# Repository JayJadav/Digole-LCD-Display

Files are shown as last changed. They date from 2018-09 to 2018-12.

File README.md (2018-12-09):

# Build Instructions - Broadcom Development Platform: Digole LCD with Touch Capabilities
#### By Jacob Ladan • For Hardware Production Technology CENG 317, Humber College School of Applied Technology
<br />

## Table of Contents
- [Introduction](#introduction)
- [Build Materials and Budget](#build-materials-and-budget)
- [Time Commitment](#time-commitment)
- [Mechanical Assembly](#mechanical-assembly)
- [PCB and Soldering](#pcb-and-soldering)
- [Powering Up Device](#powering-up-device)
- [The Software](#the-software)
- [Testing](#testing)
- [Finished Product](#finished-product)
- [Resources](#resources)
<br />

## Introduction
As a result of following these build instructions, the builder will be able to implement a Digole LCD screen with a Raspberry Pi 3B+.
These build instructions will aid the builder in producing a unified product, along with the necessary code to drive these devices. 
The builder will connect the LCD screen to the Pi with the aid of a custom designed PCB, and utilize a small program in order to read a 
string from a user through the Pi's terminal and print it to the LCD. The program will be written in C and the interface used to connect the 
Pi and the LCD will be I squared C (I2C).

The following image depicts the overall goal of the hardware project for the third year capstone of the Computer Engineering Technology 
program at Humber College. This includes two other projects that are to be implemented at a later date, as well as a communication with 
a remotely hosted database. 

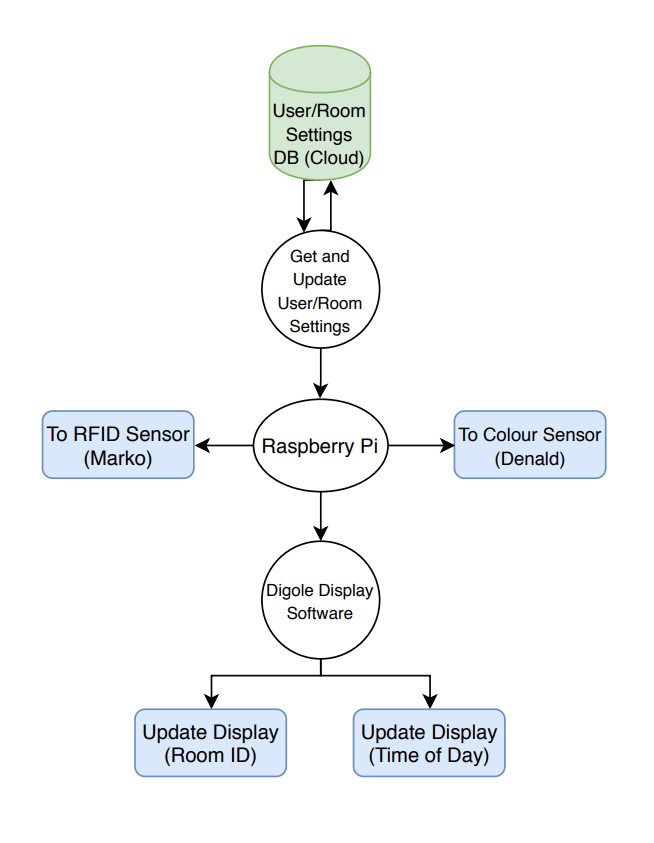
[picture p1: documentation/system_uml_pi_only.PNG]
SystemUML


For the purpose of these build instructions and what will be focused on, the following image depicts an initial version to introduce 
the builder to interfacing a Pi with an LCD screen. This allows the builder to use what has been produced through these instructions and apply it how they see fit. 

BISystemUML

#### The finished product, and what will be achieved through following these instructions.

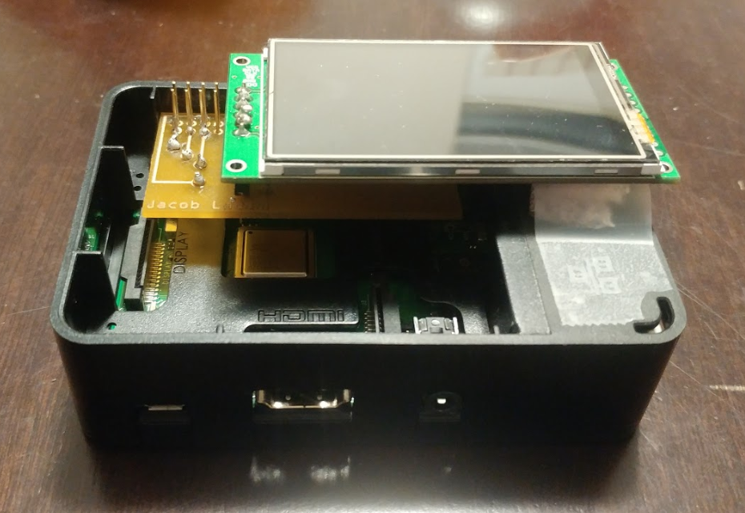
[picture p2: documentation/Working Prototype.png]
FinishedProduct


#### Helpful skills a builder should have before beginning:
- Familiarity with a linux shell environment for navigating the Raspberry Pi console
- Breadboarding
- Soldering
- Some knowledge of programming (C is most helpful)

A weekly updated blog for the fall semester of 2018 for this project as it was designed and implemented can be viewed [here](https://jacobladan.github.io/Digole-LCD-Display/).
<br />

## Build Materials and Budget
A full list of materials along with a detailed view of costs can be downloaded form within this repository [here](https://github.com/jacobladan/Digole-LCD-Display/blob/master/documentation/Budget.xlsx).
The total cost of producing this project is heavily inflated due to the cost of the soldering kit that was supplied in the lab during
development. Any generic solding iron can be used for this project.

The total cost after removing the soldering kit is: **$398.27 CAD** after HST. This includes all the tools used in completing the project (eg. wirecutters, needlenose pliers, breadboard, etc.)

Notable purchases include: Raspberry Pi 3B+ Kit ($94.95 CAD) and Digole 2.4" LCD display with touch capabilities ($17.49 USD).
<br />

## Time Commitment
A detailed view of the schedule followed this semster can be downloaded from within this repository [here](https://github.com/jacobladan/Digole-LCD-Display/blob/master/documentation/Capstone%20Gantt%20Schedule.mpp). 
This schedule uses a weekly breakdown that follows the CENG 317 class schedule for the fall semester of 2018. This project could be completed in a more compact time frame if the builder so chooses. The schedule is helpful in outlining the overall flow and the order in which each milestone for the project is completed. Orignally the project was completed over a 15 week semester, however it could more reasonably be completed in 1-2 week(s) dependant on how many of the materials the builder already possesses, access to the facilities necessary in producing the PCB, and shipping times. 
<br />

## Mechanical Assembly
Firstly, in order for the Digole LCD to use I2C communication with the Pi, one modification must be made to the screen's logic board. The builder must solder a  short between the middle and the I2C adapters as outlined in the image below.

I2CShort

Next, the following connection scheme will be used in order to connect the Digole LCD to the Raspberry Pi's GPIO pins. 

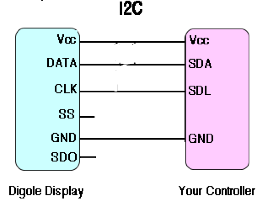
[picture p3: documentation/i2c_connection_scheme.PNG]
I2CConnection


The LCD will be connected to a breadboard, and the following connections will be made from the board to the GPIO pins on the Pi. With GPIO on the left and the coorisponding LCD connections on the right. The SS and SDO pins on the LCD will be left open:
- Pin01(3.3V) --> VCC 
- Pin03(BCM 2 Data) --> DATA
- Pin05(BCM 3 Clock) --> CLK 
- Pin06(Ground) --> GND

As a result the builder will now have produced something similar to the construction depicted below. 

BreadboardConection

Note: A 6 pin header has been soldered to the LCD's connectors in order to allow it to attach properly to the breadboard and later the PCB. 

With the Pi powered on, and I2C communications enabled, the LCD will power on and display its factory default message indicating that proper power has been supplied, ground has been connected, and the LCD is in working order. 

Next, to ensure the LCD has been connected properly for I2C communications, the following command should be entered in to the Pi's terminal: ```sudo i2cdetect -y 1```. This will display a simple graphic listing each device connected to the I2C bus and it's corrisponding address. The address the LCD uses is 0x27.

i2cdetect
<br />

## PCB and Soldering
The following PCB was designed and used for this project. The Gerber files for the PCB can be found from within this repository [here](https://github.com/jacobladan/Digole-LCD-Display/tree/master/documentation/Gerber%20Files%20V2.0). Included in these files is a save for the application **Fritzing** which was used to produce this design. This file can be opened and used by the same program to add any modifications to the board as the builder should see fit. Such as, their own name and a description. 

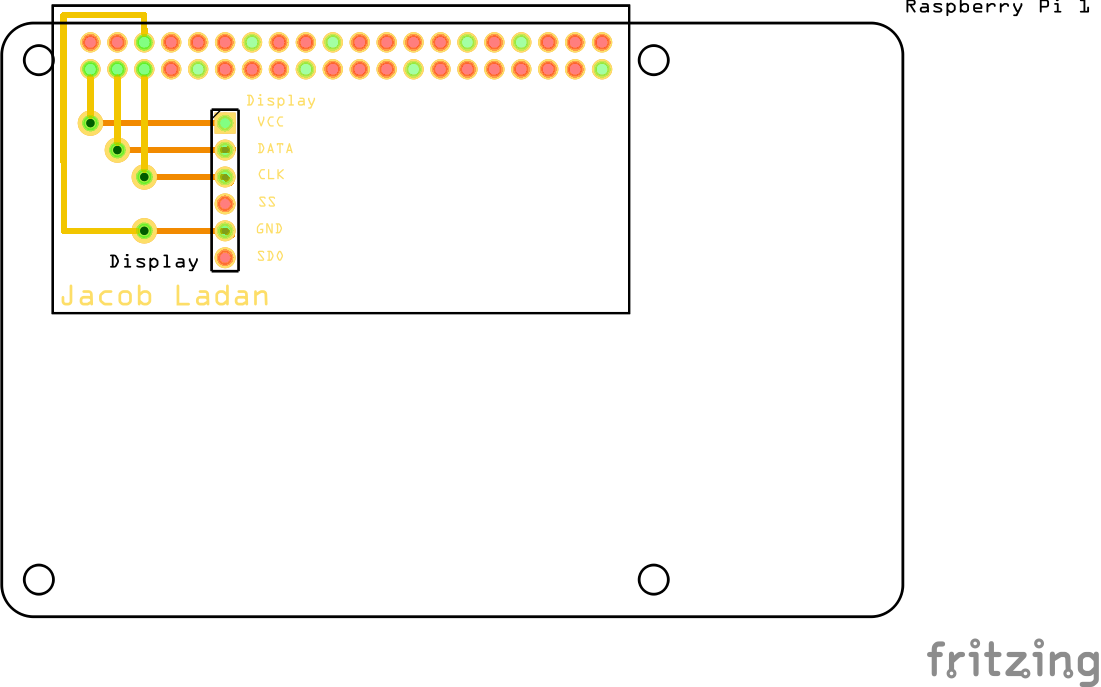
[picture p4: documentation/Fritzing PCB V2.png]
FritzingPCB


To construct the PCB, the prototype lab located at Humber College was used. However, any third party production facility may be used, as the files are universally accepted as an industry standard. The two images below show the PCB constructed from both the top and bottom. A 6 pin header has been soldered to the top of the PCB to connect to the LCD and a 40 pin header has been soldered to the bottom to connect to the GPIO pins on the Pi. Additionally, the vias (holes connecting top and bottom) have been connected by soldering a small piece of conductor through them.

#### PCB - Top
PCBTop

#### PCB - Bottom
PCBBottom

<br />

## Powering Up Device
At this point in the project, the PCB will now be connected to the Pi and the LCD will then be connected to the PCB. What the builder will have is a product resembling the end result, as depicted in the introduction of these instructions. The builder must ensure that the connections have been made properly by powering up the Pi and ensuring the screen receives power by lighting up and displaying its default message as it did in the mechanical assembly section of these instructions. Again, on the Pi enter the following command in the Pi's terminal to ensure the proper connections have been made for I2C communication: ```sudo i2cdetect -y 1```
<br />

## The Software
The C program in its entirety can be downloaded from within this repository [here](https://github.com/jacobladan/Digole-LCD-Display/blob/master/documentation/Initial%20LCD%20Testing/digoleWrite.c). Below is the source code for the program:

```
#include <unistd.h>
#include <stdio.h>
#include <fcntl.h>
#include <sys/ioctl.h>
#include <linux/i2c-dev.h>
#include <string.h>

int main(void) {
	int file_i2c;
	int addr = 0x27;
	char *filename = (char*) "/dev/i2c-1";
	char message[100] = "Hello, World!";

	printf("\nStarting connection with Digole LCD...\n");
	// Opening I2C bus connection
	if ((file_i2c = open(filename, O_RDWR)) < 0) {
		printf("\nFailed to open I2C bus.");
		return -1;
	}
	// Setting LCD address communication
	if (ioctl(file_i2c, I2C_SLAVE, addr) < 0) {
		printf("\nFailed to communicate with slave");
		return -1;
	}
	// Main loop - Asking for message with stdin and displaying it on LCD
	while(strncmp(message, "-1", 2) != 0) {
		printf("Enter a message (max 100char) or -1 to quit: ");
		fflush(stdout);
		fgets(message, sizeof(message), stdin);
		// Clearing the LCD and setting the cursor on
		write(file_i2c, "CL", 2);
		write(file_i2c, "CS1", 3);
		// Entering text write mode. Writing the message. Closing write mode
		write(file_i2c, "TT", 2);
		write(file_i2c, message, sizeof(message));
		write(file_i2c, "0", 1);
	}
	// Clearing the screen and closing I2C file
	write(file_i2c, "CL", 2);
	close(file_i2c);

	return 0;
}
```

#### Program Explaination
1. The program connects to the I2C interface by opeining a file descriptor with read and write permissions that defines the driver for I2C communications on the Pi
2. The address for communicating with the LCD is defined by using ```ioctl()``` passing the file descriptor for the driver, the definition stating that the device is an I2C slave, and the address for the device being ```0x27``` as perameters
3. The program is entered in to a loop prompting the user for a message or if they would like to exit by entering ```-1```
4. ```message``` is assigned the value of the string the user has input to the terminal, and will be used when writing to the LCD
5. ```write()``` is used to issue commands to the LCD by writing text to the I2C driver that was opened previously. ```"CL"``` is the command used to clear all the pixels and ```"CS1"``` is used to set the cursor position to the top left corner of the LCD
6. Text write mode must be entered for the LCD so that it knows to interpret the next command as to be what will be written to the screen. ```"TT"``` is used to do so
7. The ```message``` is then written to the LCD
8. Text write mode is left by issuing ```"0"``` 
9. Finally, when the user is finished with the program and enteres ```-1```, the program clears the screen with ```"CL"``` and then closes the I2C driver file
10. Program exits

#### Compiling
To compile the program using the gcc C compiler issue ```gcc digoleWrite.c -o digoleWrite``` in the terminal, making sure to be operating in the same directory as digoleWrite.c. This command compiles the program and creates an executable to be used to run the program.  
<br />

## Testing
To run the program issue ```./digoleWrite``` from within the same directory as before when compiling and the program should start. The builder should then observe the LCD clear its default message and be able to write their own messages to the screen using the program on the Pi running within its terminal. Below are two images depicting the program in action. One from the Pi's terminal, where the user enters the message to be written to the LCD, and a second displaying the message on the LCD. 

#### User Input
TerminalINput

#### LCD Output
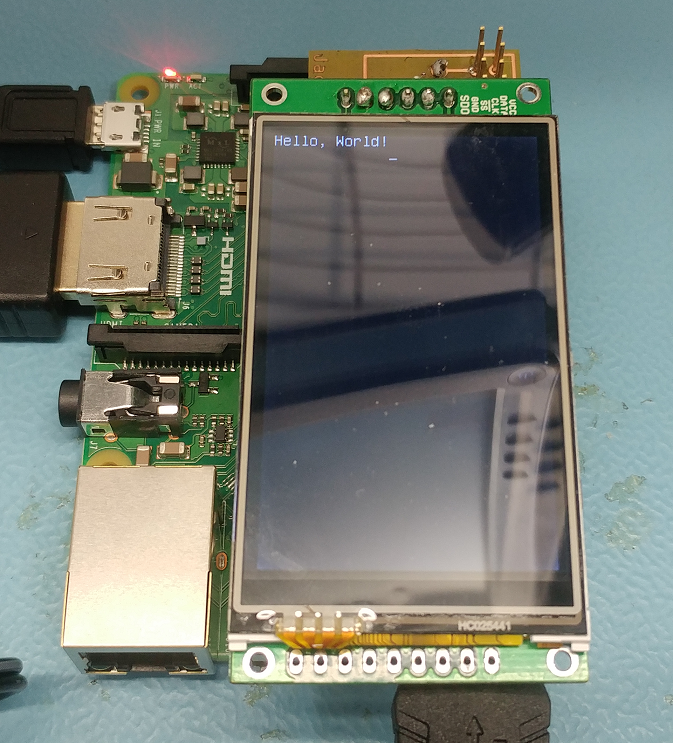
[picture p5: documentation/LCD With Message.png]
LCDOutput

<br />

## Finished Product
To complete this project, the Pi will be placed back in to the case that was purchased along side it. Making sure to remove the PCB from the pi before attempting to place the Pi in the case to avoid damage. The final product, if all the instructions were followed correctly, will be presented as such.

FinishedProduct

For additional screen support, an electronics safe foam was placed in between the case and the LCD. 
<br />

## Resources
- [Raspberry Pi Projects](http://raspberry-projects.com/pi/programming-in-c/i2c/using-the-i2c-interface)
- [Synthiam](https://synthiam.com/Tutorial/Digole-Digital-Solutions-Lcd-Displays-16344)
- Digole Digital Solutions [Programmer Manual](http://www.digole.com/images/file/Tech_Data/Digole_Serial_Display_Adapter-Manual.pdf)
- [Fritzing](http://fritzing.org/home/)
- Raspberry Pi OS [Raspbian](https://www.raspberrypi.org/downloads/raspbian/)
- Diagrams [draw.io](https://www.draw.io/)

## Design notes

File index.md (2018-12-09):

# Digole-LCD-Display
### Implementing a Digole LCD Display with a Raspberry Pi

## December 11th - Build Instructions
The build instructions have been completed and can be viewed [here](https://github.com/jacobladan/Digole-LCD-Display/blob/master/README.md) or at the root of this repository. The project for this semester has now been completed on time and within budget.

## November 27th - Presentation
Today, the project is presented to the class. The Power Point can be found [here](https://github.com/jacobladan/Digole-LCD-Display/blob/master/documentation/Presentation.pptx).

#### Schedule Update  
The [schedule](https://github.com/jacobladan/Digole-LCD-Display/blob/master/documentation/Capstone%20Gantt%20Schedule.mpp) has been followed accordingly for this week. I have finished the presentation on time and am on track to complete my build instructions by the end of the term.

#### Budget Update  
The [budget](https://github.com/jacobladan/Digole-LCD-Display/blob/master/documentation/Budget.xlsx) has been updated to reflect the final changes of each indavidual item being acquired.

## November 20th - Raspberry Pi Case

#### Acrylic Case
The schematic can be found [here](https://github.com/jacobladan/Digole-LCD-Display/blob/master/documentation/RPI%20Case%20Schem.cdr). 

#### 2D Case Render
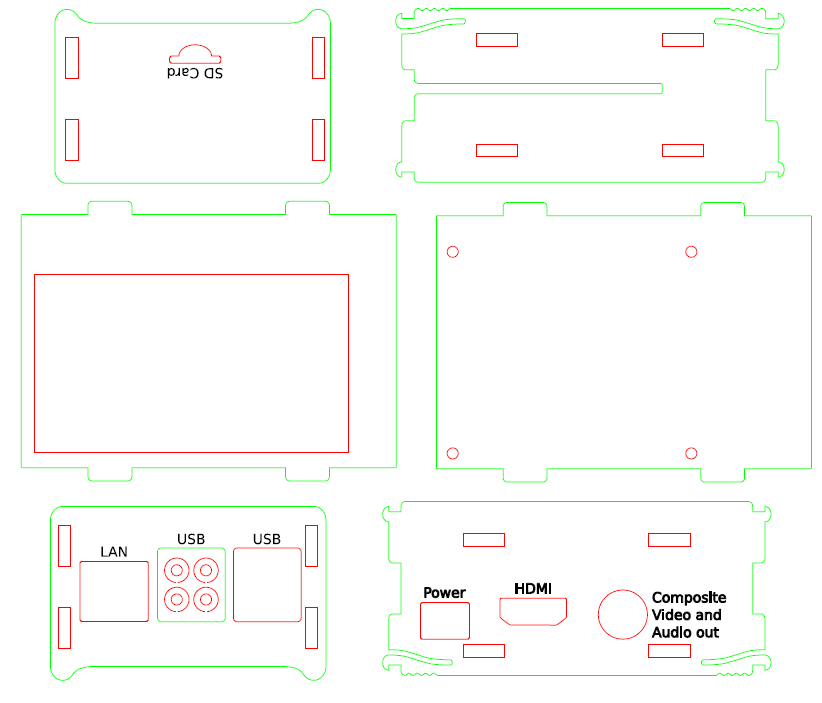
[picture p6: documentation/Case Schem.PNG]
2DCase


After getting my case laser cut, some glaring problems were observed. While I had resized the sides/top/bottom to accommodate the addition of the LCD display, I had neglected to take in to account that the indiavidual slots on each peice would be moved as well. As a result, each piece did not fit together and the case could not be constructed. Below is a picture of my second option, that being to use the original case the Raspberry Pi came with and attach the screen to the top. In the future a cover will be added to the top of the device in order to protect the electronic components inside.  

#### Pi with LCD
PiandLCD

#### Schedule Update  
The [schedule](https://github.com/jacobladan/Digole-LCD-Display/blob/master/documentation/Capstone%20Gantt%20Schedule.mpp) has been followed accordingly for this week. I was able to succesfuly design and send in my schematic to the prototype lab for cutting. After having to use my backup plan for the case, I was able to remain on schedule.

#### Budget Update  
The [budget](https://github.com/jacobladan/Digole-LCD-Display/blob/master/documentation/Budget.xlsx) has not been changed as of this date.

## November 13th - PCB Completed and LCD Testing
This week I received my updated version 2 of the PCB now with the correct number of ports and connections. I soldered the vias together, and attached two pin headers for both the GPIO pins on the Pi and the 6 pins for my LCD screen. These headers are being used so the devices aren't permanently soldered to the board and PCB. Below are two images of the PCB after soldering (front and back).

#### PCB Front
PCBFront

#### PCB Back
PCBBack

After solding and connecting both the PCB and the LCD to the Pi I was able to compile a [simple C script](https://github.com/jacobladan/Digole-LCD-Display/blob/master/documentation/Initial%20LCD%20Testing/digoleWrite.c) to read in a string from the terminal and write it to the LCD. The below images show the script running.

#### Terminal Input
TerminalInput

#### LCD Output
TerminalOutput

#### Schedule Update  
After having to make up the time lost redesigning and soldering a new PCB I have returned to the proper place in the [schedule](https://github.com/jacobladan/Digole-LCD-Display/blob/master/documentation/Capstone%20Gantt%20Schedule.mpp) and remain on track to complete this project by December 11th. 

#### Budget Update  
The [budget](https://github.com/jacobladan/Digole-LCD-Display/blob/master/documentation/Budget.xlsx) has not been changed as of this date.

## November 6th - PCB Design Update
As I began soldering the vias together I noticed that I didn’t account for the GND pin not being placed adjacent to the CLK pin on the display. As such, I was required to move the ground connection on the PCB over one port. Also, I reconfigured the total number of ports on the PCB to match the amount of pins that the display has. In other words I added a sixth port to account for the SS pin. The SS pin and the SDA pin will be left open. The files were sent to the Prototype Lab and the PCB should be constructed by the 8th.

#### Fritzing Breadboard
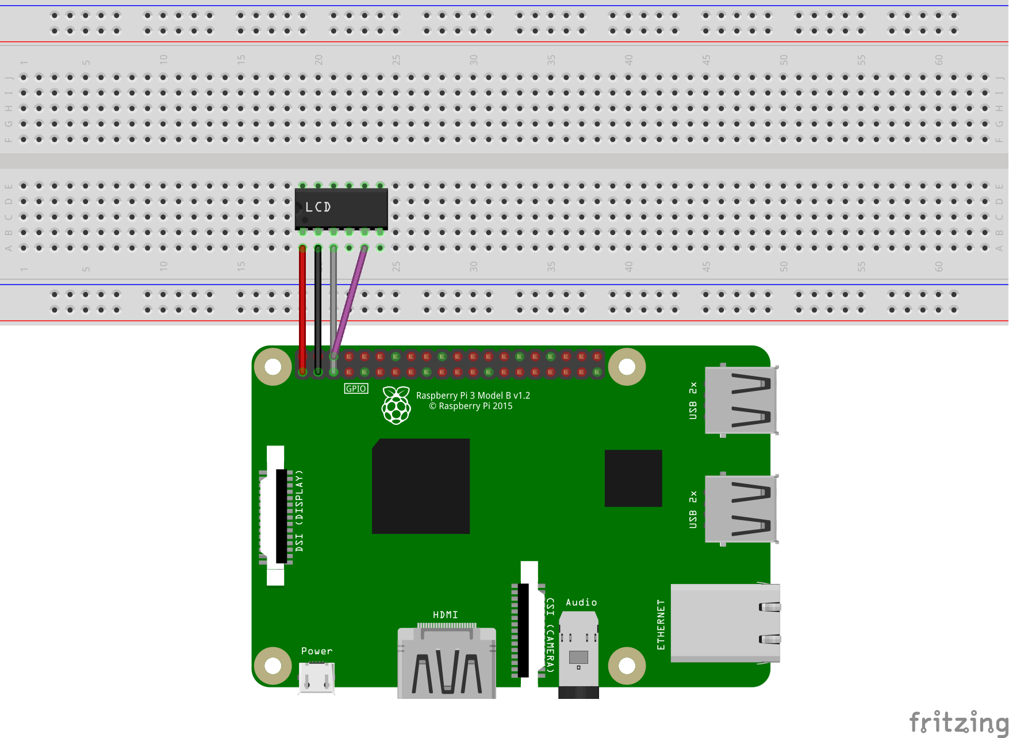
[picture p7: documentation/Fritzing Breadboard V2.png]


#### Fritzing Schematic
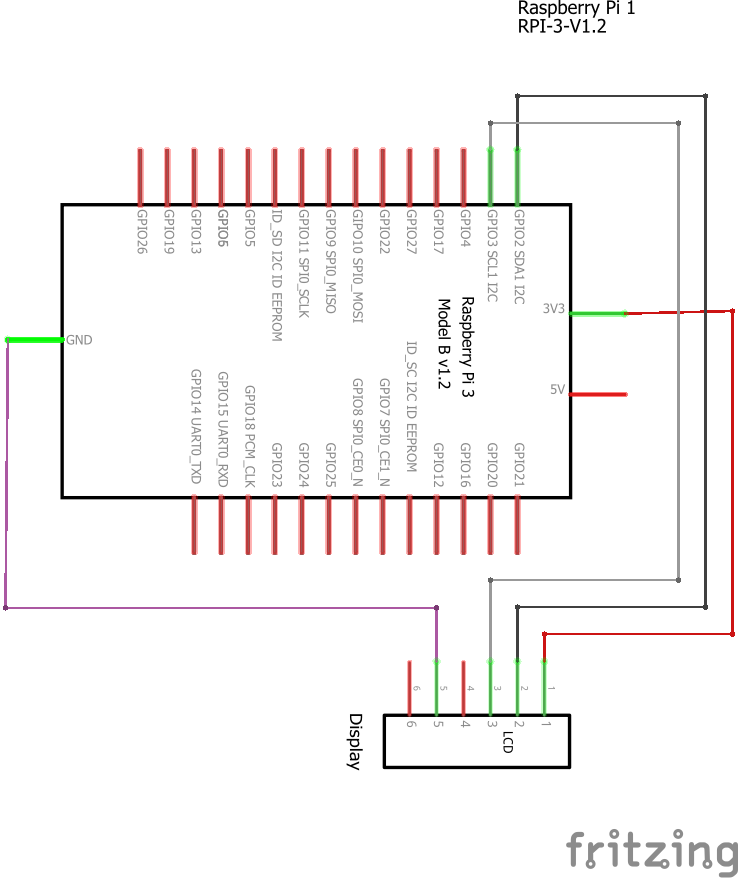
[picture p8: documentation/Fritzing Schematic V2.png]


### Fritzing PCB
FritzPCB

### Soldering top of PCB V1
FritzPCB

### Soldering Bottom of PCB V1
FritzPCB

#### Schedule Update  
As I was unable to complete the soldering task laid out in the [schedule](https://github.com/jacobladan/Digole-LCD-Display/blob/master/documentation/Capstone%20Gantt%20Schedule.mpp) by the end of this week's lab period I will now be completing it on my own time by the end of day on November 9th. This will keep me on track for next week when we will be deomstrating our sensors/effectors.

#### Budget Update  
The budget has not been changed as of this date. Budget can be viewed [here](https://github.com/jacobladan/Digole-LCD-Display/blob/master/documentation/Budget.xlsx).

## October 30th - PCB Design
#### Fritzing Breadboard
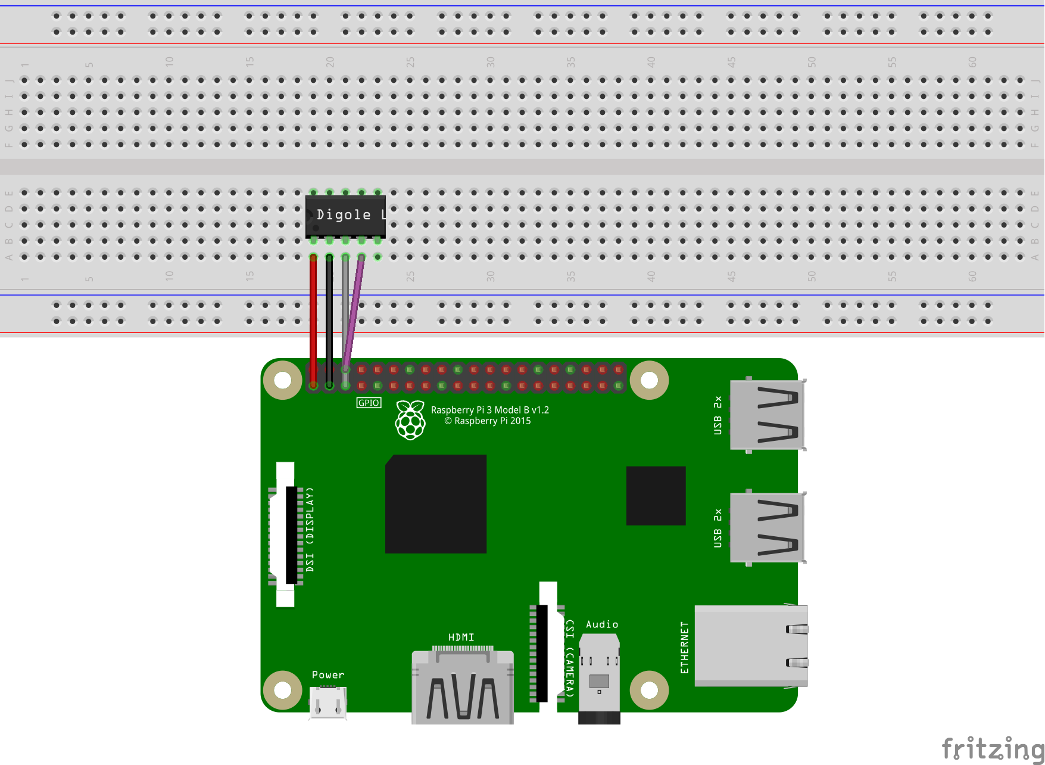
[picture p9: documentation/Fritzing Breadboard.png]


#### Fritzing Schematic
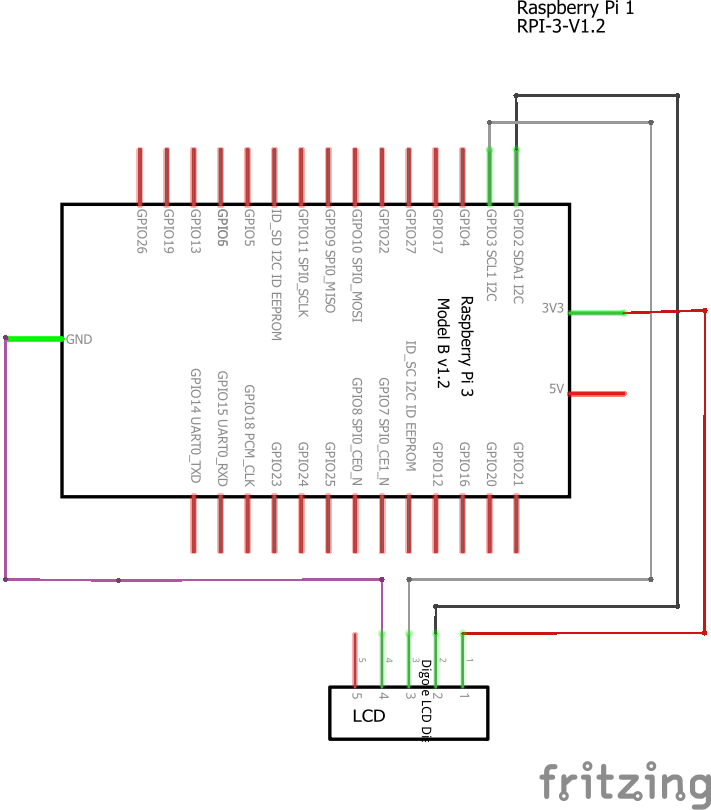
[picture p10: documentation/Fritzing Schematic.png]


### Fritzing PCB
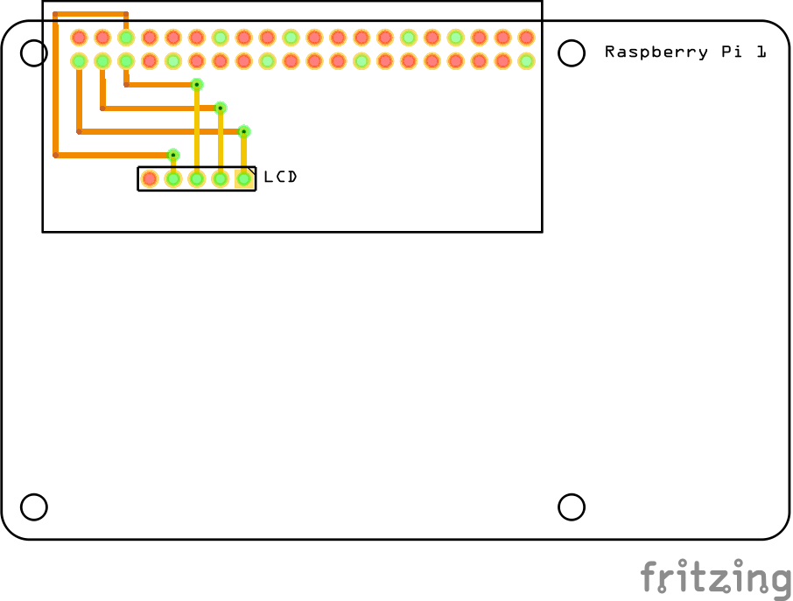
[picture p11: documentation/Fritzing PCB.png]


#### Schedule Update  
I am on schedule as it is laid out [here](https://github.com/jacobladan/Digole-LCD-Display/blob/master/documentation/Capstone%20Gantt%20Schedule.mpp). The PCB Design has been completed and my Gerber files have been sent in for production.

#### Budget Update  
The budget has not been changed as of this date. Budget can be viewed [here](https://github.com/jacobladan/Digole-LCD-Display/blob/master/documentation/Budget.xlsx).

## October 23rd - Breadboarding
#### Below is a picture of the breadboard circuit set up with my screen powered on. 
#### Connection: 
- Pin01(3.3V) = VCC 
- Pin03(BCM 2 Data) = DATA
- Pin05(BCM 3 Clock) = CLK 
- Pin06(Ground) = GND

Breadboarding

#### Below shows that my Raspberry Pi does indeed see my Digole Display on my correct address of 0x27

I2cdetect

Initially I ran in to an issue of connecting to the wrong ground and power pins on my Pi. I switched from 5V to 3v3 and adjusted the ground so it was on a closer pin. 

#### To assemble this circuit I used  
[Digole Documentation](https://www.digole.com/images/file/Tech_Data/Digole_Serial_Display_Adapter-Manual.pdf)  
[Pinout Diagram](https://pinout.xyz/pinout/i2c)  

#### Schedule Update  
I am on schedule as it is laid out [here](https://github.com/jacobladan/Digole-LCD-Display/blob/master/documentation/Capstone%20Gantt%20Schedule.mpp). Breadboarding was to be done by the 23rd, and it has been completed on time. 

#### Budget Update  
The budget has not been changed as of this date. Solder has been borrowed from the Prototype Lab and the acrylic casing will be acquired on the date laid out in the schedule.

## October 16th - System UML Diagram
The system UML diagram can be viewed [here](https://github.com/jacobladan/Digole-LCD-Display/blob/master/documentation/System%20UML%20Diagram.pdf)

## October 9th - Holiday

## October 2nd - Proof of purchase
### Raspberry Pi 3B+
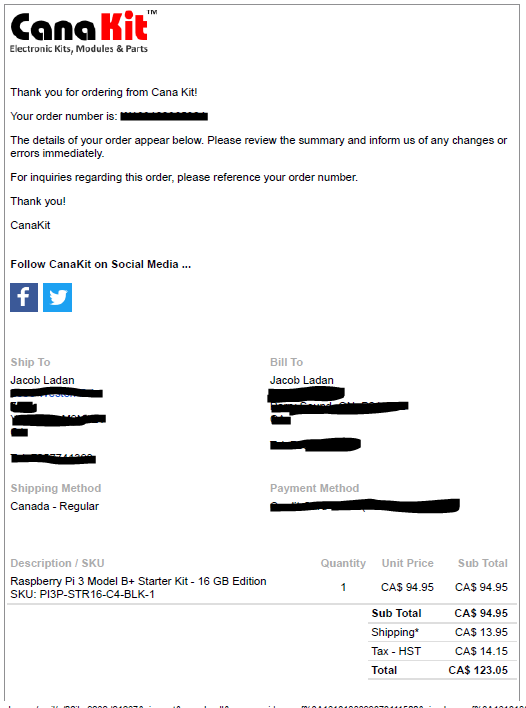
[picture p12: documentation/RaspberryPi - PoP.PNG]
Raspberry Pi POP


### Digole 2.4" LCD Display
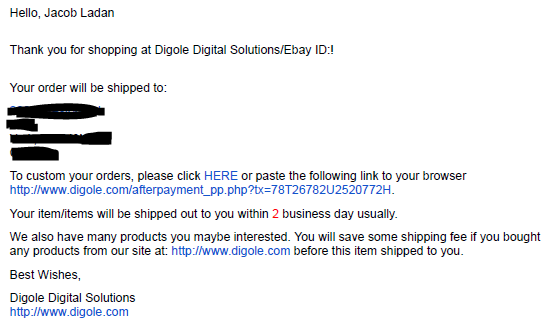
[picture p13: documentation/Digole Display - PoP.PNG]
Digole LCD POP


## September 25th - Budget
The budget can be viewed [here](https://github.com/jacobladan/Digole-LCD-Display/blob/master/documentation/Budget.xlsx).

## September 18th - Project schedule
The project schedule can be viewed [here](https://github.com/jacobladan/Digole-LCD-Display/blob/master/documentation/Capstone%20Gantt%20Schedule.mpp).

## September 11th - Project proposal
The project proposal can be viewed [here](https://github.com/jacobladan/Digole-LCD-Display/blob/master/documentation/Project%20Proposal.xlsx).

## September 4th - Project started
Welcome!

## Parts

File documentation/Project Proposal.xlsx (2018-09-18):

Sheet: DataEntry
Submission Date | 2018-11-27
Project Name | Digole LCD Display
Student Name | Jacob Ladan
Project repository | https://github.com/jacobladan/Digole-LCD-Display
SensorEffector choice | 2.4" Serial: UART/I2C/SPI 400x240 TFT with Touchscreen Module DS400240CTFT-61T
The database will store | Employee/Student Information (ID, name, email)
The mobile device functionality will include | Employee/Student information and accessibility management
I will be collaborating with the following company/department | Humber College Security Services. Humber College School of Applied Technology
My group in the winter semester will include | Marko Javorac, Denald Demirxhiu
50 word problem statement | This project should allow easier access to information about employee/student locations with respect to labs and classrooms. As well as give a detailed display of lab schedules, and current occupants. All the information will accessable over cloud based technologies.
100 words of background | The 2.4" Digole LCD Display uses a 400x240 pixel density to display images and videos with an appropriate resolution needed for our project. The device allows for UI customization with different colours and fonts. As well as implementing a touch screen which will be used for navigating different screens to access information and options.
Current product APA citation | Neets Touch Panel (Last Updated: Aug . 14th, 2018) Retrieved From: https://www.neets.dk/product/neets-touch-panel-neets-touch-panel-7b
Existing research IEEE paper APA citation | B. A. Alabdulsalam, F. A. Alsalman, Z. H. Alshakhs, H. F. Ahmad and A. Mughal, "Dynamic Video Wall Tile Creation Using Raspberry Pi3," 2017 IEEE 13th International Symposium on Autonomous Decentralized System (ISADS), Bangkok, 2017, pp. 268-271. doi: 10.1109/ISADS.2017.45 keywords: {LED displays;liquid crystal displays;screens (display);source code (software);dynamic video wall tile creation;Raspberry Pi3;PiWall system;source code;LCD monitors;LED monitors;Computers;Linux;Graphics processing units;Monitoring;Portals;Streaming media;Multimedia communication;piwall;video wall;raspberry pi;tiles}, URL: http://ieeexplore.ieee.org/stamp/stamp.jsp?tp=&arnumber=7940251&isnumber=7931239
Brief description of planned purchases | 2.4" Digole LCD with Touchscreen Capabilities, Raspberry Pi 3B+, PN532 NFC/RFID Reader
Solution description | Our solution will implement an LCD touch screen at room entrances to display schedules, and information about current occupants. It will also utilize NFC/RFID readers to allow access to restricted labs through the use of epmployee/student wrist bands implementing NFC/RFID chips.

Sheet: DataBase
Submission Date | Project Name | Student Name | Project repository | SensorEffector choice | The database will store | The mobile device functionality will include | I will be collaborating with the following company/department | My group in the winter semester will include | 50 word problem statement | 100 words of background | Current product APA citation | Existing research IEEE paper APA citation | Brief description of planned purchases | Solution description
43431 | Digole LCD Display | Jacob Ladan | https://github.com/jacobladan/Digole-LCD-Display | 2.4" Serial: UART/I2C/SPI 400x240 TFT with Touchscreen Module DS400240CTFT-61T | Employee/Student Information (ID, name, email) | Employee/Student information and accessibility management | Humber College Security Services. Humber College School of Applied Technology | Marko Javorac, Denald Demirxhiu | This project should allow easier access to information about employee/student locations with respect to labs and classrooms. As well as give a detailed display of lab schedules, and current occupants. All the information will accessable over cloud based technologies. | The 2.4" Digole LCD Display uses a 400x240 pixel density to display images and videos with an appropriate resolution needed for our project. The device allows for UI customization with different colours and fonts. As well as implementing a touch screen which will be used for navigating different screens to access information and options. | Neets Touch Panel (Last Updated: Aug . 14th, 2018) Retrieved From: https://www.neets.dk/product/neets-touch-panel-neets-touch-panel-7b | B. A. Alabdulsalam, F. A. Alsalman, Z. H. Alshakhs, H. F. Ahmad and A. Mughal, "Dynamic Video Wall Tile Creation Using Raspberry Pi3," 2017 IEEE 13th International Symposium on Autonomous Decentralized System (ISADS), Bangkok, 2017, pp. 268-271. doi: 10.1109/ISADS.2017.45 keywords: {LED displays;liquid crystal displays;screens (display);source code (software);dynamic video wall tile creation;Raspberry Pi3;PiWall system;source code;LCD monitors;LED monitors;Computers;Linux;Graphics processing units;Monitoring;Portals;Streaming media;Multimedia communication;piwall;video wall;raspberry pi;tiles}, URL: http://ieeexplore.ieee.org/stamp/stamp.jsp?tp=&arnumber=7940251&isnumber=7931239 | 2.4" Digole LCD with Touchscreen Capabilities, Raspberry Pi 3B+, PN532 NFC/RFID Reader | Our solution will implement an LCD touch screen at room entrances to display schedules, and information about current occupants. It will also utilize NFC/RFID readers to allow access to restricted labs through the use of epmployee/student wrist bands implementing NFC/RFID chips.

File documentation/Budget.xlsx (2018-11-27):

Digole Display Project Budget
Name | Description | ID | Supplier | Price/Unit (CAD) | Price/Unit (USD) | Quantity | Taxes | Customs | Shipping | Subtotal | Owned
Raspberry Pi 3 Model B+ Starter Kit | Raspberry Pi 3 Model B+ (B Plus), USB MicroSD Card Reader, CanaKit 2.5A Micro USB Power Supply, Raspberry Pi 3 Case, HDMI Cable with CEC support, 2 Aluminum Heat Sinks, GPIO Quick Reference Card | PI3P-STR16-C4-BLK | CanaKit, www.canakit.com | $94.95 | $0.00 | 1 | $12.34 | $0.00 | $13.95 | $107.29 | √
2.4" Serial Touch Screen | UART/I2C/SPI 400x240 TFT with Touchscreen Module DS400240CTFT-61T | NA | Digole Digital Solutions, www.digole.com | $18.78 | $17.49 | 1 | $0.00 | $0.00 | $2.19 | $19.68 | √
Breadboard | Self-Adhesive (830 Tie Point White) | 0160-PRT | Canada Robotix, www.canadarobotix.com | $4.99 | $0.00 | 1 | $0.65 | $0.00 | $8.99 | $14.63 | √
Hook-up Wire - Red | 22 AWG, 60°C, 300V, 25' | PRT-08023 ROHS | Spark Fun, www.sparkfun.com | $2.50 | $0.00 | 1 | $0.33 | $0.00 | $4.74 | $7.57 | √
Hook-up Wire - Black | 22 AWG, 60°C, 300V, 25' | PRT-08022 ROHS | Spark Fun, www.sparkfun.com | $2.50 | $0.00 | 1 | $0.33 | $0.00 | $4.74 | $7.57 | √
Jumper Wires | Jumper Wire Kit 140pcs | PRT-0014 ROHS | Spark Fun, www.sparkfun.com | $5.95 | $0.00 | 1 | $0.77 | $0.00 | $4.74 | $11.46 | √
Mastercraft Autoranging Digital Multimeter | 11 functions and full ranges, 2 Leads | 052-0052-2 | Canadian Tire, www.canadiantire.com | $27.99 | $0.00 | 1 | $3.64 | $0.00 | $0.00 | $31.63 | √
Electronic Parts Kit | Parts include: Resistors, capacitors, transistors, wires, diodes | NA | Humber Book Store | $120.00 | $0.00 | 1 | $15.60 | $0.00 | $0.00 | $135.60 | √
Wire Stripper | Ideal 45-120 T Stripper for solid and stranded | B000JKWVXA | Amazon, www.amazon.ca, by: Ideal | $33.45 | $0.00 | 1 | $4.35 | $0.00 | $0.00 | $37.80 | √
Solering Iron Kit | Pace MBT 350 Multi Channel Rework System with PS-90 Iron, MT-100 Tweezer and SX-100 Desoldering Iron | 8007-0551 | T Equipment, www.tequipment.net | $2068.10 | $0.00 | 1 | $268.85 | $0.00 | $0.00 | $2336.95 | √
Solder | Bernzomatic Rosin Core Solder 8.0oz | 058-6000-8 | Canadian Tire, www.canadiantire.com | $14.99 | $0.00 | 1 | $1.95 | $0.00 | $0.00 | $16.94 | √
Clear Acrylic 12"x24" | Clear Acrylic Sheet | NA | Johnson Industrial, www.johnstonplastics.com | $7.18 | $0.00 | 1 | $0.93 | $0.00 | $0.00 | $8.11 | √
By: Jacob Ladan
 |  |  |  | Total Owned | $2735.22
 |  |  |  | Total Unowned | $0.00
 |  |  |  | Total | $2735.22
 |  |  |  | USD to CAD | $1.29

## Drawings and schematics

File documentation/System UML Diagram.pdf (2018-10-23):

# Hadware Production - System UML Diagram

### By: Jacob Ladan

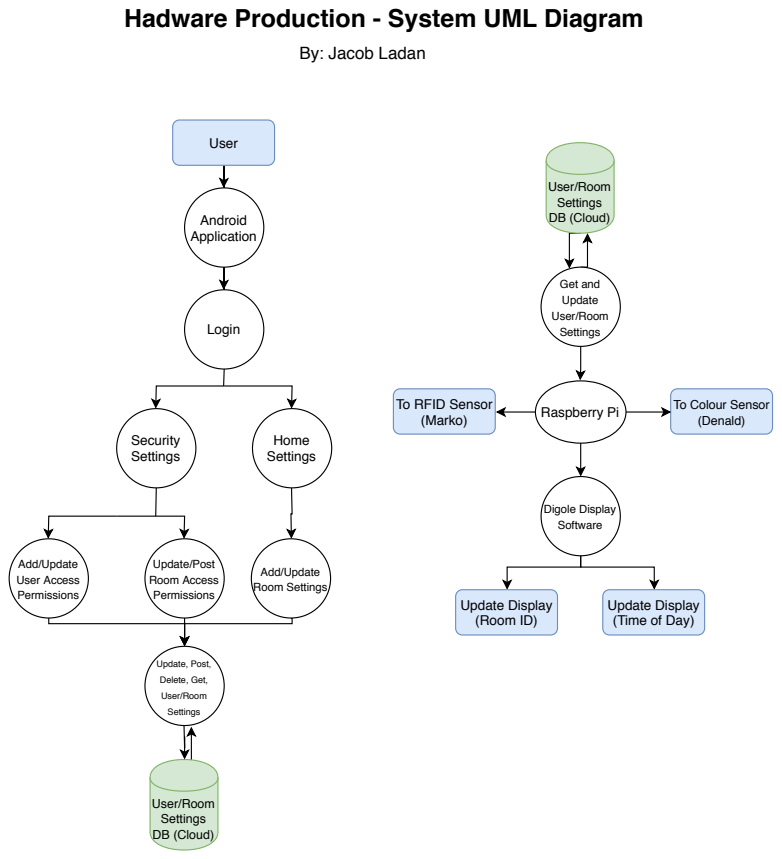
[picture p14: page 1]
User; Android Application; Login; Security Settings; Home Settings; Add/Update User Access Permissions; Update/Post Room Access Permissions; Add/Update Room Settings; User/Room Settings DB (Cloud); Update, Post,; Delete, Get,; User/Room; Settings; Get and Update User/Room Settings; Digole Display Software; Update Display (Room ID)

To RFID Sensor
(Marko)

(Denald) Raspberry Pi

To Colour Sensor

Update Display
(Time of Day)

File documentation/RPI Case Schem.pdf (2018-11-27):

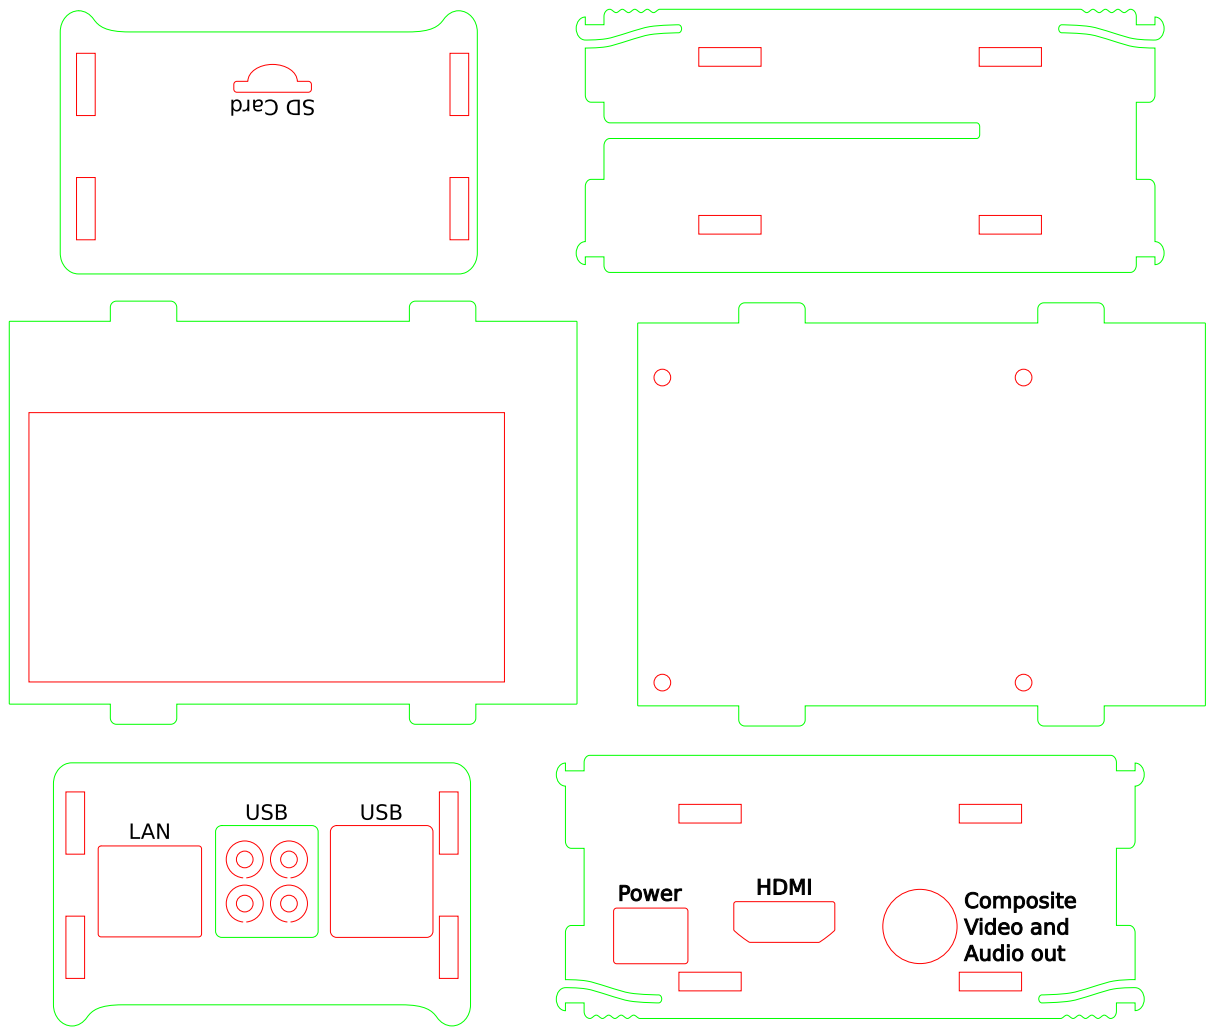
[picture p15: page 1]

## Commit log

2018-09-18 Added documentation and proposal
    [Project Proposal.xlsx]
2018-09-25 Adding budget
    [Budget.xlsx]
2018-10-23 Added pictures to show breadboarding and i2c connection
2018-10-30 Added PCB Design
    [Untitled Sketch_contour.gm1, Untitled Sketch_copperBottom.gbl, Untitled Sketch_copperTop.gtl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]
2018-11-06 Version 2 of PCB
    [Digole-LCD-Display Fritzing_contour.gm1, Digole-LCD-Display Fritzing_copperBottom.gbl, Digole-LCD-Display Fritzing_copperTop.gtl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]
2018-11-06 Added soldering on PCB V1
2018-11-13 Added finished PCB and testing script
2018-11-20 Added pi case schematic
2018-11-26 Added working prototype case
2018-11-27 Presentation and updated budget
    [Budget.xlsx]
2018-12-08 Added up to and including mechanical assembly
2018-12-08 Added PCB and Soldering
2018-12-08 Modified: i2c_short
2018-12-08 Changed i2c short file
